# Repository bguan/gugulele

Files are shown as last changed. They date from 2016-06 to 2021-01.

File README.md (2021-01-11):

# Gugulele (G6)
OpenSCAD scripts to generate parametric 3D models of gourd shaped ukuleles suitable for 3D printing.  Check out some of the generated models here:

 * https://www.thingiverse.com/thing:1868201
 * http://www.thingiverse.com/thing:1007035
 * http://www.thingiverse.com/thing:1057746
 * http://p3d.in/kLuhJ/xray+spin

## Usage
1. include G6 into an openscad project

   e.g. In a new OpenSCAD file my-uke.scad
 ```
include <../G6.scad>;
```
2. override any parameters in G6-params.scad
   e.g. In my-uke.scad
 ```
include <../G6.scad>;

// Overriding Default Rendering Resolution Params
HIRES = 30; 
DEFRES = 20; 
LORES = 20;

// High level params
MODEL = 3;
HEAD_STYLE = 2;
F_GAP = 90;
B_GAP = 90; 
C_GAP = 90; 
USE_SCREWS = true;
SNDHOLE_STYLE = 6;
SPINE_STYLE = 2;   
BRACE_STYLE = 2;   
TUNER_STYLE = 3;
PICKUP_STYLE = 1;
SHOW_LOGO = true; 
```
3. run and see the generated result!

   e.g. from command line
 ```
 > openscad -o my-uke.stl my-uke.scad
 > open my-uke.stl
```

## Warning
If you set the resolution as suggested in the example above, it could take a few minutes to generate the rough looking output STL file. This is often sufficient for debugging and preview. If you want a nice looking file for 3D printing, I would suggest setting HIRES to 180 or above, DEFRES to 30 or above, and LORES to 20 or above.  This configuration may take hours to render, at least until OpenSCAD can optimize its performance with effective multi-threading.

## Credits
G6 uses the excellent Nuts n Bolts library (https://github.com/JohK/nutsnbolts) to render screws and holes.

If you use G6 to generate and print a ukulele successfully please give credit to G6 and shoot me an email! brian dot guan at gmail dot com.

## Random Thoughts
The hardest part for me is to deal with the lack of spline in OpenSCAD.  I have to subtract scaled arc from rectangle and revolve it to get to a funnel shape for the shoulder, and similarly scaled different quadrants of sphere to get an ellipsoid.  Also due to "functional" nature of OpenSCAD, I have to contort the fret calculation by using some crazy recursive function.  Filleting also is a challenge as I have to accomplish that with Minkowski sum of small sphere
and the main parts with sharp edges.

The most painful part is that OpenSCAD is painfully slow when rendering at high resolution, as it is single threaded and not utilizing GPU unlike professional 3D CAD tools.  I have ported this to OnShape Feature Script. See the [Gugulele public document] (https://cad.onshape.com/documents/5d1958b45f2484ebebb64adf/w/d0b2164f9e843f6c6ce251e7/e/505e487213bab5c385cd9bb5) there.

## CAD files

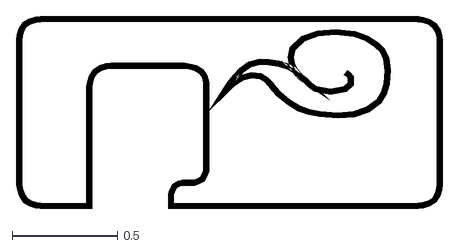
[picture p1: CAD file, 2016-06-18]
logo-no-text-wavy.dxf
2.03 x 0.917

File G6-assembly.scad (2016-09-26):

//////////////////////////// 
// Gugulele 6 Assembly 
////////////////////////////

module assemble() {
    saddle_ht = BRDG_SET + BRDG_TCK + SDDL_RAD;
    nut_ht = FRETBD_HD_TCK + F0_RAD;
    f12_ht = FRETBD_HD_TCK + tan(FRETBD_RISE)*SCALE_LEN/2 + FRET_RAD;
    str12_ht = nut_ht + (saddle_ht - nut_ht)/2;
    body_rad = body_rad(NECK_LEN, NECK_HEAD_WTH, NECK_SLOPE, SHOULDER_FLARE) ;
    torso_len = torso_len(NECK_LEN, NECK_HEAD_WTH, NECK_SLOPE, SCALE_LEN, SHOULDER_FLARE) ;
    butt_len = butt_len(NECK_LEN, NECK_HEAD_WTH, NECK_SLOPE, SCALE_LEN, SHOULDER_FLARE, FRONT_BACK_RATIO) ;
    front_scale = front_scale(NECK_LEN, NECK_HEAD_WTH, NECK_SLOPE, SCALE_LEN, SHOULDER_FLARE); 
    back_scale = back_scale(NECK_LEN, NECK_HEAD_WTH, NECK_SLOPE, SCALE_LEN, SHOULDER_FLARE, FRONT_BACK_RATIO);
    
    echo(str("scale_len = ", SCALE_LEN, 
            ", Action at 12th fret = ", str12_ht - f12_ht));
    echo(str("body_rad = ", body_rad, ", front_scale = ", front_scale, ", back_scale = ", back_scale));
    echo(str("TOP_SCALE = ", TOP_SCALE, ", BOTTOM_SCALE = ", BOTTOM_SCALE));
    difference() {
        
        union() {
            body();
            
            if (SHOW_HEAD) {
                head(NECK_HEAD_WTH, HEAD_STEM, 0);
            }
    
            if (SHOW_FRETBD) {
                translate([0, 0, F_GAP])  fretboard();
            }
    
            if (SHOW_FRETS) {
                translate([0,0, F_GAP]) 
                rotate([0, -FRETBD_RISE, 0])
                lay_frets_from_nut(F1_LEN, F1_LEN / SEMI_RATIO, 1);
            }
    
            if (SHOW_BRIDGE) {
                translate([SCALE_LEN +N_GAP +S_GAP, 0, BRDG_SET  +B_GAP]) 
                    bridge(is_cut = false); 
            }
            
            if (SHOW_GUIDE && (HEAD_STYLE==0 || HEAD_STYLE==2)) {
                translate([STR_GUIDE_PLCMT +N_GAP +S_GAP, 0, 
                         BRDG_SET -STR_GUIDE_SET_OFF_BRDG +G_GAP]) 
                    strings_guide(); 
            }
            
            if (SHOW_STRINGS) {
                translate([0, 0, F_GAP]) strings();
            }
            
            if (SHOW_BRACE ) {
				translate([0, 0, -FIT_TOL])
                if (BRACE_STYLE == 1) {
                    xbrace(body_rad, butt_len);
                } else if (BRACE_STYLE == 2) {
                    tbrace(body_rad, butt_len);
                }
            }
        }
    
        if (SHOW_LOGO) {
            logo();
        }
        
        if (SPINE_STYLE>0 && 
		   (SHOW_SHOULDER_TOP || SHOW_SHOULDER_BOTTOM || SHOW_TOP || SHOW_BOTTOM || SHOW_HEAD || SHOW_FRETBD)) {    
            echo(str("spine_len = ", SPINE_LEN, ", or ", SPINE_LEN/INCH_TO_MM, " inches"));
            place_spine(is_cut = true);
        }
        
        if (SHOW_HEAD && HEAD_STYLE == 1 && USE_HEAD_PIN) {
            for (hpx = H_GAP > 0 ? [-H_GAP, 0] : [0]) {
                translate([hpx, 0, -5-V_GAP])
                rotate([0, 90-HEAD_ANGLE, 0]) {
                    translate([0, 0, -55])
                    rotate([0, 180, 0]) {
                        cylinder(h=100, r=5);
                        screw(HEAD_PIN_MODEL, thread="no");
                    }
                }
            }
        }
        
        if (SHOW_CUTOUT) {
            translate([-100, 0, -V_GAP -body_rad -C_GAP])
                cube([2*SCALE_LEN +N_GAP +S_GAP, 2*body_rad, 2*body_rad +V_GAP +F_GAP +C_GAP]);
        }
        
        if (SHOW_CROSS_SECTION) {
            translate([SCALE_LEN, -2*body_rad, -V_GAP -2*body_rad -C_GAP])
                cube([2*SCALE_LEN, 4*body_rad, 4*body_rad +V_GAP +F_GAP +C_GAP]);
        }
        
        if (SHOW_FRETBD && SHOW_FRETDECO) {
            translate([0, 0, F_GAP])  
            rotate([0, -FRETBD_RISE, 0]) 
                deco_frets_from_nut(F1_LEN, F1_LEN / SEMI_RATIO, 1, true);
        }
            
    }
        
    if (SHOW_PEGS) {
        if (HEAD_STYLE==0 || HEAD_STYLE==2) {
            translate([N_GAP +S_GAP, 0, -TUNER_BD_TCK -FIT_TOL]) 
                tail_pegs(is_cut = false);
        } else {
            translate([-H_GAP, 0, -V_GAP]) 
                rotate([0, -HEAD_ANGLE, 0]) 
                    pegs(is_cut = false);
        }
    }
    
    if (SPINE_STYLE>0 && SHOW_SPINE) {    
        place_spine(is_cut = false);
    }
    
    if (SHOW_PICKUP) {
        place_pickup(is_cut = false);
    }
}

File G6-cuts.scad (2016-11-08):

///////////////////////// 
// Gugulele 6 Cuts
//////////////////////////

module back_cover(body_rad, bot_scale, front_scale, back_scale, is_cut=false) {
    brad = BACK_COVER_RATIO * body_rad + (is_cut ? FIT_TOL : 0);
    irad = brad -3*BACK_SCREW_HEAD_RAD + (is_cut ? FIT_TOL : 0);
    //tck = is_cut ? 1.4 : bot_scale*brad;
    //itck = is_cut ? .75*bot_scale*brad : 1.4;
    tck = is_cut ? 1.5: bot_scale*brad;
    itck = is_cut ? 1.5*bot_scale*brad : 1;
    rndrad = BOT_RND_RAD; //.65;
    orad = BOT_RND_RAD; //.65;
    side_scale = BACK_COVER_SIDE_SCALE;
    
    rotate([0, BACK_COVER_ANGLE, 0])
    translate([0, 0, -BACK_COVER_PLCMT]) {
        difference() {
            union() {
                scale([1, side_scale, 1]) {

                    // inner oval
                    translate([0, 0, -FUSE_SHIFT]) {
                        difference() {
                            scale([front_scale, 1, 1]) {
                                if (is_cut) {
                                    cylinder(r=irad, h=itck, $fn=HIRES);
                                } else {
                                    minkowski() {
                                        cylinder(r=irad-rndrad, h=itck-.9*rndrad, $fn=HIRES);
                                        if (rndrad > 0) sphere(r=1.1*rndrad, $fn=LORES);
                                    }
                                }
                                funnel(rndrad, irad);
                            }
                            translate([0, -2*brad, -2*brad]) cube([4*brad, 4*brad, 4*brad]);
                        }
                        
                        scale([CHAMBER_BACK_RATIO*back_scale, 1, 1]) {
                            if (is_cut) {
                                cylinder(r=irad, h=itck, $fn=HIRES);
                            } else {
                                minkowski() {
                                    cylinder(r=irad-rndrad, h=itck-.9*rndrad, $fn=HIRES);
                                    if (rndrad > 0) sphere(r=1.1*rndrad, $fn=LORES);
                                }
                            }
                            funnel(rndrad, irad);
                        }
                    }
                    
                    // outer oval
                    translate([0, 0, 2*FUSE_SHIFT -tck]) {
                        difference() {
                            scale([front_scale, 1, 1]) {
                                minkowski() {
                                    cylinder(r=brad -rndrad, h=tck-rndrad, $fn=HIRES);
                                    if (rndrad > 0) sphere(r=rndrad, $fn=LORES);
                                }
                                if (is_cut) {
                                    translate([0, 0, FUSE_SHIFT-orad]) 
                                        funnel(orad, .999*brad);
                                    translate([0, 0, 2*FUSE_SHIFT-brad-orad]) 
                                        cylinder(r=2*brad, h=brad, $fn=HIRES);
                                } 
                            }
                            translate([0, -2*brad, -2*brad]) cube([4*brad, 4*brad, 4*brad]);
                        }
                        scale([CHAMBER_BACK_RATIO*back_scale, 1, 1]) {
                            minkowski() {
                                cylinder(r=brad -rndrad, h=tck-rndrad, $fn=HIRES);
                                if (rndrad > 0) sphere(r=rndrad, $fn=LORES);
                            }
                            if (is_cut) {
                                translate([0, 0, FUSE_SHIFT-orad]) 
                                    funnel(orad, .999*brad);
                                translate([0, 0, 2*FUSE_SHIFT-brad-orad]) 
                                    cylinder(r=2*brad, h=brad, $fn=HIRES);
                            } 
                        }
                    }
                }
            }
            
            if (!is_cut && USE_SCREWS) {
                for(fb =[1, -1]) {
					for(lr = fb > 0 ? [-.5, .5] : [-1, 1]) {
						translate([fb*(-(fb >0 ?front_scale :CHAMBER_BACK_RATIO*back_scale)*brad +4*BACK_SCREW_HEAD_RAD), 
								lr*4*ENDPIN_RAD, -2])
						rotate([180, 0, 0])
						union() {
							cylinder(r=BACK_SCREW_HEAD_RAD, h=10);
							screw(BACK_SCREW_MDL, thread=SCREW_THREAD);
						}
					}
                }
                
                for(lr =[-1, 1]) {
                    translate([-.1*BODY_RAD, 
                        lr*(side_scale*brad -1.5*BACK_SCREW_HEAD_RAD), 
                        -2])
                    rotate([180, 0, 0])
                    union() {
                        cylinder(r=BACK_SCREW_HEAD_RAD, h=10);
                        screw(BACK_SCREW_MDL, thread=SCREW_THREAD);
                    }
                }
            }
        }
        
        if (is_cut && USE_SCREWS) {
            for(fb =[1, -1]) {
				for(lr = fb > 0 ? [-.5, .5] : [-1, 1]) {
					translate([fb*(-(fb >0 ?front_scale :CHAMBER_BACK_RATIO*back_scale)*brad +4*BACK_SCREW_HEAD_RAD), 
							lr*4*ENDPIN_RAD, -2])
					rotate([180, 0, 0])
					union() {
						cylinder(r=BACK_SCREW_HEAD_RAD, h=10);
						screw(BACK_SCREW_MDL, thread=SCREW_THREAD);
					}
				}
            }
            
            for(lr =[-1, 1]) {
                translate([-.1*BODY_RAD, 
                    lr*(side_scale*brad -1.5*BACK_SCREW_HEAD_RAD), 
                    -2])
                rotate([180, 0, 0])
                union() {
                    cylinder(r=BACK_SCREW_HEAD_RAD, h=10);
                    screw(BACK_SCREW_MDL, thread=SCREW_THREAD);
                }
            }
        }
    }
}

                
module oval_holes(body_rad, front_scale, xlen, ylen) {
    for (lr = (SNDHOLE_STYLE >= 8 ? [-1] :[-1, 1])) {
        translate([0, lr*body_rad*OVAL_WIDEN_RATIO, 0])
        rotate([0, 0, lr*OVAL_ANGLE])
        scale([xlen/ylen, 1, 1])
        cylinder(r =ylen, h = body_rad);
    }
}

module peg_anchor(anchor_dx = 0, anchor_dy = 0, is_cut = true) {
    cut_adj = is_cut ? FIT_TOL : 0;    

	// anchor pins
	if (ANCHORPIN_RAD > 0) {
		translate([anchor_dx, anchor_dy, -2*TUNER_BD_TCK]) 
			cylinder(h=TUNER_BD_TCK+ANCHORPIN_DEP+cut_adj, 
				r=ANCHORPIN_RAD +cut_adj);
	}
}
    
module peg(anchor_dx = 0, anchor_dy = 0, is_cut = true) {
    top_rnd_rad = HEAD_STYLE == 1 ? 2*HD_RND_RAD : TOP_RND_RAD +BOT_RND_RAD >0 ? 2*TOP_RND_RAD : 0;
    bot_rnd_rad = HEAD_STYLE == 1 ? 2*HD_RND_RAD : TOP_RND_RAD +BOT_RND_RAD >0 ? 2*BOT_RND_RAD : 0;
    cut_adj = is_cut ? FIT_TOL : 0;    
	peg_res = 2*DEFRES;
    
    difference() {
        union() {
            // top counter hole
            minkowski() {
				translate([0, 0, top_rnd_rad -FIT_TOL])
            		cylinder(h=2*TUNER_BD_TCK, 
							r=TUNER_TOP_RAD +(top_rnd_rad > 0 ? 0 :cut_adj),
							$fn=peg_res);
				if (top_rnd_rad > 0) sphere(r=top_rnd_rad, $fn=LORES);
			}
            
            // main shaft
            translate([0,0,-TUNER_BD_TCK -FIT_TOL]) 
            cylinder(h=TUNER_BD_TCK +2*FIT_TOL, 
					r=TUNER_HOLE_RAD +cut_adj +max(top_rnd_rad, bot_rnd_rad), 
					$fn=peg_res);
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

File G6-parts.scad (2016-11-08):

//////////////////////// 
// Gugulele 6 Body Parts 
//////////////////////////

// neck by layer, 0 is top, 1 is bottom
module neck(layer, front_scale, nlen, nwth, nslope, top_scale, bot_scale) {
    neck_tl_wth = nwth +2*nlen*nslope;
    prelen = FIT_TOL + nlen/front_scale;
    ntw = neck_tl_wth + FIT_TOL*2*nslope;
    planes = [-neck_tl_wth-1, 0];
    scales = [top_scale, bot_scale];
	scale([front_scale, 1, scales[layer] ]) difference() {
		translate([prelen, 0, 0]) rotate([0, -90, 0])
			cylinder(r2=nwth/2, r1=ntw/2, h=prelen, $fn=HIRES);
		translate([-1, -ntw/2 -1, planes[layer]]) 
			cube([prelen+2, ntw+2, ntw+1]);
	}        
}

// shoulder by layer, 0 is top, 1 is bottom
module shoulder(layer, front_scale, shoulder_len, torso_len, shoulder_curve_R, 
                shoulder_rtop, shoulder_rbot, shoulder_atop, shoulder_abot, 
                top_scale, bot_scale) {
    prelen = shoulder_len/front_scale;
    tlen = torso_len/front_scale;
    planes = [-2*shoulder_rbot-1, 0];
    scales = [top_scale, bot_scale];
    scale([front_scale, 1, scales[layer] ]) 
    difference() {
        translate([prelen, 0, 0]) 
        rotate([0, -90, 0]) 
        funnel(shoulder_curve_R, shoulder_rtop, shoulder_atop, shoulder_abot);
        
        translate([-1, -shoulder_rbot -1, planes[layer]]) 
        cube([prelen+2, 2*shoulder_rbot+2, 2*shoulder_rbot+1]);
    }
}

module torso(layer, front_scale, torso_len, body_rad, 
            top_scale, bot_scale) {
    tlen = torso_len/front_scale;
    planes = [-body_rad-1, 0];
    scales = [top_scale, bot_scale];
    scale([front_scale, 1, scales[layer] ]) difference() {
        translate([tlen, 0, 0]) 
            sphere(r=body_rad, $fn=HIRES);
        translate([-1, -body_rad -1, planes[layer]]) 
            cube([2*body_rad+2, 2*body_rad+2, body_rad+1]);
        translate([-2*body_rad, -body_rad -1, -body_rad-1]) 
            cube([2*body_rad, 2*body_rad+2, 2*body_rad+2]);
        translate([tlen, -body_rad -1, -body_rad-1]) 
            cube([2*body_rad+1, 2*body_rad+2, 2*body_rad+2]);
    }
}

module butt(layer, back_scale, body_rad, top_scale, bot_scale) {
    scale([back_scale, 1, (layer == 0 ? top_scale : bot_scale)] ) 
    rotate([(layer == 0 ? 0 : 180), 0, 0 ])
        quartersphere(body_rad, res=HIRES);
}


            
// The Main Gourd Shape that could be used as neck+body and head
module gourd(layers, nlen, nwth, nslope, mlen, flare, back_ratio, top_scale, bot_scale) {
                
    shoulder_rtop = shoulder_rtop(nlen, nwth, nslope);
    shoulder_atop = shoulder_atop(nslope);
    shoulder_abot = shoulder_abot(nslope, flare);
    shoulder_curve_R = shoulder_curve_R(nlen, nwth, nslope, flare); 
    shoulder_rbot = shoulder_rbot(nlen, nwth, nslope, flare); 

    body_rad = body_rad(nlen, nwth, nslope, flare); 
    front_scale = front_scale(nlen, nwth, nslope, mlen, flare); 
    back_scale = back_scale(nlen, nwth, nslope, mlen, flare, back_ratio);
    shoulder_len = shoulder_len(nlen, nwth, nslope, mlen, flare); 
    torso_len = torso_len(nlen, nwth, nslope, mlen, flare);
    butt_len = butt_len(nlen, nwth, nslope, mlen, flare, back_ratio);

    for (i=layers) {
        translate([0, 0, i == 0 ? -FUSE_SHIFT : 0]) 
            neck(i, front_scale, nlen, nwth, nslope, top_scale, bot_scale);
    
        translate([nlen -FUSE_SHIFT, 0, (i==0 ? -FUSE_SHIFT : 0)])
            shoulder(i, front_scale, shoulder_len, torso_len, 
                shoulder_curve_R, shoulder_rtop, shoulder_rbot,
                shoulder_atop, shoulder_abot, 
                top_scale, bot_scale);
        
        translate([nlen + shoulder_len -2*FUSE_SHIFT, 0, (i==0 ? -FUSE_SHIFT : 0) ] )
            torso(i, front_scale, torso_len, body_rad, 
                top_scale, bot_scale); 
    
        translate([nlen + shoulder_len + torso_len -3*FUSE_SHIFT, 0, (i==0 ? -FUSE_SHIFT : 0) ])
            butt(i, back_scale, body_rad, top_scale, bot_scale); 
    }
}

                
module dovetail(is_cut=false) {
    cut_adj = is_cut ? FIT_TOL : 0;
    trapezoid(NECK_JOINT_WTH2 +2*cut_adj, NECK_JOINT_WTH1 +2*cut_adj, 
              NECK_JOINT_TCK +2*cut_adj, NECK_JOINT_TCK +2*cut_adj, 
              NECK_JOINT_LEN +2*cut_adj);

	translate([0, 0, (is_cut ? FUSE_SHIFT: 0)])
	scale([1, 1, .25])
	difference() {
		rotate([0, 90, 0])
		cylinder(r2=NECK_JOINT_WTH1/2 +cut_adj, r1=NECK_JOINT_WTH2/2 +cut_adj, h=NECK_JOINT_LEN +2*cut_adj);

		translate([0, -200, 0]) cube([400, 400, 400]);
	}
}

module shoulder_joint(is_cut=false) {
    cut_adj = is_cut ? 2*FIT_TOL : 0;
	difference() {
		hull() 
		for(ud = [0, -1]) {
			for(lr = [-1, 1]) {
				translate([(SHOULDER_JNT_LEN+cut_adj)/2, 
							lr*(SHOULDER_JNT_WTH+cut_adj)/2, 
							ud*(SHOULDER_JNT_TCK+cut_adj)-(V_GAP > 0 ? 0 : SHOULDER_JNT_TCK/3)]) 
					rotate([0, 0, 90])
					round_rod(SHOULDER_JNT_LEN+cut_adj, 1);
			}
		}

		if (V_GAP > 0) {
			translate([-500, -500, 0])
			cube([1000, 1000, 1000]);
		}
	}
}

module body() {

    shoulder_rtop = shoulder_rtop(NECK_LEN, NECK_HEAD_WTH, NECK_SLOPE);
    shoulder_atop = shoulder_atop(NECK_SLOPE);
    shoulder_abot = shoulder_abot(NECK_SLOPE, SHOULDER_FLARE);
    shoulder_curve_R = shoulder_curve_R(NECK_LEN, NECK_HEAD_WTH, NECK_SLOPE, SHOULDER_FLARE); 
    shoulder_rbot = shoulder_rbot(NECK_LEN, NECK_HEAD_WTH, NECK_SLOPE, SHOULDER_FLARE); 

    body_rad = BODY_RAD;
    shoulder_len = shoulder_len(NECK_LEN, NECK_HEAD_WTH, NECK_SLOPE, SCALE_LEN, SHOULDER_FLARE); 
    torso_len = torso_len(NECK_LEN, NECK_HEAD_WTH, NECK_SLOPE, SCALE_LEN, SHOULDER_FLARE);
    front_scale = BODY_FRONT_SCALE;
    back_scale = BODY_BACK_SCALE;
    
    chamber_rad = body_rad - BODY_TCK;
    chamber_front_scale = CHAMBER_BODY_RATIO*front_scale;
    chamber_back_scale = CHAMBER_BODY_RATIO*back_scale*CHAMBER_BACK_RATIO;
    
    top_front_vol = PI*(chamber_front_scale*chamber_rad)*(CHAMBER_TOP_SCALE*chamber_rad)*chamber_rad/3;
    top_back_vol = PI*(chamber_back_scale*chamber_rad)*(CHAMBER_TOP_SCALE*chamber_rad)*chamber_rad/3;
    bot_front_vol = PI*(chamber_front_scale*chamber_rad)*(CHAMBER_BOTTOM_SCALE*chamber_rad)*chamber_rad/3;
    bot_back_vol = PI*(chamber_back_scale*chamber_rad)*(CHAMBER_BOTTOM_SCALE*chamber_rad)*chamber_rad/3;
    chamber_vol = top_front_vol +top_back_vol +bot_front_vol +bot_back_vol;
    echo(str("Chamber volume = ",chamber_vol, "(mm^3)"));
    
    // subtract spine & brace?
    chmb_len = chamber_rad*(chamber_front_scale + chamber_back_scale);
    echo(str("chamber len = ", chmb_len, "mm"));
    spine_vol_chmb = (SPINE_STYLE >=2 ? SPINE_HT*SPINE_WTH*chmb_len*(SPINE_GAP > 0 ? 2 : 1) : 0);
    echo(str("spine_vol_chmb = ", spine_vol_chmb, "mm^3"));
    brace_vol_chmb = [0, 2*chmb_len*BRACE_LEN_RATIO*BRACE_WTH, 
						chmb_len*BRACE_LEN_RATIO*body_rad*BRACE_SPAN_RATIO][BRACE_STYLE]; 
    echo(str("brace_vol_chmb = ", brace_vol_chmb, "mm^3"));
    adj_chmb_vol = chamber_vol -spine_vol_chmb -brace_vol_chmb; 
    echo(str("adjusted chamber volume = ", adj_chmb_vol, "mm^3"));
    
    hook_wth = HOOK_WTH_RATIO*body_rad;
    hook_len = HOOK_LEN_RATIO*torso_len;
    fholes_area = 2 *2 *hook_area(hook_wth, hook_len);
    
    top_hole_rad = TOP_HOLE_RATIO*body_rad;
    top_hole_area = PI*pow(top_hole_rad, 2);
    
    oval_len = OVAL_LEN_RATIO*body_rad; //1.4*front_scale*.12*body_rad;
    oval_wth = OVAL_WTH_RATIO*body_rad;
    sgl_o = PI * oval_len * oval_wth;
    dbl_o = 2*sgl_o;
    
    harea = ([0, fholes_area, top_hole_area, dbl_o, sgl_o][(SNDHOLE_STYLE -SNDHOLE_STYLE%2)/2])/
            pow(1000, 2);
    hvol = adj_chmb_vol/pow(1000,3);
    
    /* from
       http://www.acousticmasters.com/AcousticMasters_GuitarBody2.htm
       https://newt.phys.unsw.edu.au/jw/Helmholtz.html
    */

    max_tck = body_rad*TOP_SCALE -chamber_rad*CHAMBER_TOP_SCALE 
                -CHAMBER_UP_SHIFT +CHAMBER_FRONT_SHIFT*tan(CHAMBER_TILT) ;
    sndbd_tck = max_tck;
    echo(str("sndbd_tck (mm): ", sndbd_tck));

    tube_len = sndbd_tck + 1.7*[0, 
								hook_len, 
								top_hole_rad, 
								oval_len+oval_wth, 
								(oval_len+oval_wth)/2
							   ][(SNDHOLE_STYLE -SNDHOLE_STYLE%2)/2];

    helmholz_freq = (SND_AIR_SPEED * sqrt(harea/(hvol * .001*tube_len)))/(2 *PI);
    echo(str("helmholz_freq = ", helmholz_freq, "hz"));
    echo(str("adjusted helmholz_freq = ", .98*helmholz_freq, "hz"));
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

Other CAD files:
G6-specs.scad
Baritone_Decohead_3pc_long/Baritone_H2R2X1S8T3P1_3pc.scad
Baritone_Headed_3pc/M4H1R2X2S8T1_FB.scad
Concert_Decohead_3pc/Concert_H2R2X2S8T4_FB.scad
Concert_Decohead_X_3pc/Concert_H2R2X1S8T3_FB.scad
G6-test.scad
G6-utils.scad
G6.scad
Guitar_Decohead_4pc/Guitar_H2R2X1S2T3_FBS.scad
Guitar_Decohead_FB/Guitar_H2R2X1S8T1P1_FB.scad
Guitar_Decohead_FBC/Guitar_H2E2X1S2T1P1_FBC.scad
Guitar_Decohead_FBNV/Guitar_H2R2X1S2T3P2_FBNV.scad
Guitar_Decohead_X_FBNSV/Guitar_H2R2X1S2T3P2_FBNSV.scad
Pocket_headed_1pc/Pocket_H2X2S8T2.scad
Soprano_Decohead_4pc/Soprano_H2R2X1S8T3_FBS.scad
Soprano_Decohead_8pc/Soprano_H2R2X2S6T3P1_8pc.scad
Tenor_Decohead_FB/Tenor_H2R2X1S8T3_FB.scad
Tenor_Decoheadless_Backcover_4pc/Tenor_H2R2X2S6T0P1C_4pc.scad

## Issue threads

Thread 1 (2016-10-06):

Trying to create a Baritone with Head

sanjeev002, 2016-10-06:
Hi,

Thanks for these script they work really well for soprano models.

I am trying to create a Baritone with head for normal closed geared tuners.

I find that when I generate the head it seems to be chopped off. The chop off section seems to go through the tuners furthest from the Nut.

Is there anything I am doing wrong?

Is there any way to reduce the size of the body on a baritone?

Thanks

bguan, 2016-10-06:
HI Sanjeev,

Thanks for trying it out, and I am impressed you can even get it to work in the first place :-)

I am sure you are not doing anything wrong, it is likely to be bug in my code, as a headed baritone is not one of my usual test model.

I will look into it.

bguan, 2016-10-07:
Fixed with /bguan/gugulele/commit/0a244856c3023fd6428cc29b5f1301fe5f35b7bd

Closed 2016-10-07.

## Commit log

2016-03-17 Initial commit of library and example scripts
    [G6-assembly.scad, G6-cuts.scad, G6-params.scad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]
2016-03-24 Allow separate rounding radius for top and bottom layer
    [G6-test.scad]
2016-03-24 Second commit for files missed from previous: allow separate rounding radius for top and bottom layer
    [G6-cuts.scad, G6-params.scad, G6-parts.scad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]
2016-03-24 Rename Tenor Model files to reflect correct Tuner choice 3 (instead of 0)
    [Tenor_H2R2X2S6T3P1C_4pc.scad]
2016-03-24 Update README.md
    Add link to a online 3D viewer of a generated model: Tenor size gourd shaped ukulele with decorative head, embedded tail planetary banjo style tuners, openable back cover, thru-body rectangular spine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
2016-03-25 Added another config/model for a 7pc Tenor
    [Tenor_H2R2X2S6T3P1_7pc.scad]
2016-03-25 Fix bugs with neck gap, vertical gap. Add rounded bottom to thicken neck joint.
    [G6-cuts.scad, G6-params.scad, G6-parts.scad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]
2016-04-02 Fix various little bugs and adjustments for other models and cut permutations
    [G6-assembly.scad, G6-cuts.scad, G6-params.scad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]
2016-04-02 Added Guitar, and 2 Soprano uke models
    [Guitar_H2R2X2S6T3P1C_4pc.scad, Soprano_H1R2X2S6T1_1pc.scad, Soprano_H2R2X2S6T1_8pc.scad]
2016-04-02 Modifications to 7pc Tenor
    [Tenor_H2R2X2S6T3P1_7pc.scad]
2016-04-05 Minot edits
    [G6-cuts.scad, G6-params.scad, G6-parts.scad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]
2016-04-11 Tweaks for the Soprano 8pc design
    [G6-cuts.scad, G6-params.scad, Soprano_H2R2X2S6T1_8pc.scad]
2016-05-18 Many tweaks incl. optimization to restricting minkowski only on the butt end of the uke, ensuring seamless join with body uding intersection of stretched cylinder.
    [G6-assembly.scad, G6-cuts.scad, G6-params.scad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]
2016-05-26 Experiments with various ways to perform rounding of edges, while ensuring seamless joints.
    [G6-cuts.scad, G6-params.scad, G6-parts.scad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]
2016-06-18 Lots of mods and sample models.
    [Baritone_H2R2X1S8T3P1_3pc.scad, Concert_H2R2X1S8T3_FB.scad, Concert_H2R2X2S8T4_FB.scad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]
2016-06-18 Mods to scripts.
    [G6-cuts.scad, G6-params.scad, G6-parts.scad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]
2016-08-05 Slight modifications incl changing T4 to UPTL
    [G6-cuts.scad, G6-params.scad, G6-parts.scad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]
2016-08-06 Thicken spines.
    [G6-parts.scad]
2016-08-19 Minor mods.
    Tuners always have uplift regardless of V_GAP.
    Thinner neck joints.
    Tail tuner fanout calculation is more precise.
    [G6-cuts.scad, G6-params.scad, G6-parts.scad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]
2016-08-20 Added Shoulder GAP support to allow further splitting for small printer.
    New param S_GAP and SHOULDER_SPLIT_RATIO.
    Small tweaks all around.
    [G6-assembly.scad, G6-cuts.scad, G6-params.scad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]
2016-08-20 Added Sample Guitar using Shoulder Split.
    [Guitar_H2R2X1S2T3P2_FBNSV.scad]
2016-08-20 Added Long Butt Tenor
    [Tenor_H2R2X1S8T3L_FB.scad]
2016-08-22 Rename Params to Spec and simplify shoulder joint.
    [G6-specs.scad]
2016-09-26 Minor edits all over the place
    [G6-assembly.scad, G6-cuts.scad, G6-parts.scad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]
2016-09-26 Added more demo files
    [Guitar_H2E2X1S2T1P1_FBC.scad, Guitar_H2R2X1S2T3P2_FBNV.scad, Guitar_H2R2X1S2T3_FBS.scad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]
2016-09-26 slight mod of pocket script
    [Pocket_H2X2S8T2.scad]
2016-09-26 minor mods to soprano
    [Soprano_H2R2X1S8T3_FBS.scad]
2016-09-28 Lots of fixes and house cleaning
    [M1H2R2X1S2T4_HNSFVBG.scad, Tenor_H2R2X1S8T3_FB.scad]
2016-09-29 House keeping
    [G6-cuts.scad, G6-parts.scad, G6-specs.scad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]
2016-09-29 Minor mods
    [G6-parts.scad, G6-specs.scad]
2016-10-07 Fixed issue 1: Headed Baritone
    Lots of minor fixes, incl. Bridge code for various String Tie styles.
    Added example Headed Baritone.
    [M4H1R2X2S8T1_FB.scad]
2016-10-09 Tune oval hole sizes to frequencies G, F, E, D, C, A by Model
    [G6-cuts.scad, G6-parts.scad, G6-specs.scad]
2016-10-24 Minor fixes and Helmholtz adjustments
    [G6-cuts.scad, G6-parts.scad, G6-specs.scad]
2016-10-25 set TUNER_BD_TCK to 12 so both gotoh UPT or UPTL can be used.
    [G6-specs.scad]
2016-10-26 Define High and Low Res based on Default.
    [G6-specs.scad]
2016-10-26 clean up params
    [G6-specs.scad]
2016-10-27 Minor tweaks
    [G6-specs.scad]
2016-10-28 Tweaks to tuner and head specs
    [G6-specs.scad]
2016-10-28 Tweak X-Brace settings
    [G6-parts.scad, G6-specs.scad, M1H2R2X1S2T4_HNSFVBG.scad]
2016-11-04 Minor fixes
    [Concert_H2R2X1S8T3_FB.scad, G6-parts.scad, G6-specs.scad]
2016-11-08 Minor tweaks. Adjusted Helmholtz calc for all sndhole styles.
    [G6-cuts.scad, G6-parts.scad, G6-specs.scad]
2016-11-15 Tweak specs a little.
    [G6-specs.scad]
